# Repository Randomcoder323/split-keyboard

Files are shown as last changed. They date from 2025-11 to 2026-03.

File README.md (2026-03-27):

# split-keyboard

## Build!
This project was very fin to build, I had a few obstacles with the code and soldering, especially the battery. But in the end I finished and got it to work. Some keys don't fully work, but I really like how this turned out!





IMG_0612 (1)
IMG_0611 (1)

## Intro
Hello! This is my third blueprint project. After finishing the LED chaser and Hackpad, I wanted something more challenging. So I chose a keyboard. If you want to access my journals, here is the link:

[My Blueprint Journals](https://blueprint.hackclub.com/projects/1863)

---

## BOM Pictures






https://github.com/user-attachments/assets/b1c73c75-90e0-4224-99fa-895c186426c0





---

## CAD



<p align="center">
  CAD screenshot 1
</p>

<p align="center">
  CAD screenshot 2
</p>

---

## PCB + Schematics

<p align="center">
  PCB screenshot 1
</p>

<p align="center">
  PCB screenshot 2
</p>

<p align="center">
  PCB screenshot 3
</p>

---

## BOM Table

*to optimize cost and lower it i had to get 10 keyswitches fro aliexpress and rest from amazon to avoid payingg fro 70pc.

| Component | Cost (USD) | Link | Notes |
|---|---|---|---|
| PCB | 21.24 | https://jlcpcb.com | See screenshot in README |
| Seeed Studio XIAO x2 | 19.69 | https://www.aliexpress.us/item/3256808140543257.html | Free shipping; screenshots from AliExpress |
| Keycaps | 14.32 | https://www.aliexpress.us/item/3256809092009723.html | Free shipping |
| Switches | 26.26 | https://www.aliexpress.us/item/3256806440445666.html | Amazon + AliExpress |
| Amazon link for above |  | https://www.amazon.com/gp/product/B0FCYKV41M |  |
| Diodes | 0.99 | https://www.aliexpress.us/item/3256805857667344.html | Free shipping |
| Battery | 5.86 | https://www.aliexpress.us/item/3256808925051634.html | Free shipping |
| 3D printed parts | 0.00 | N/A | Shipped with another project |
| Resistors | 3.60 | https://www.aliexpress.us/item/3256806851785003.html | Three types, no shipping |
| Pins for MCU | 2.06 | https://www.aliexpress.us/item/2255800687544049.html | For the microcontroller |
| **Total** | **94.02** |  |  |

---

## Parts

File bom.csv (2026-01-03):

Component | Cost (USD) | Link | Notes
PCB | 21.24 | Jlcpcb.com | See screenshot in README
Seeed Studio XIAO x2 | 19.69 | https://www.aliexpress.us/item/3256808140543257.html?mp=1 | Free shipping; screenshots from AliExpress
Keycaps | 14.32 | https://www.aliexpress.us/item/3256809092009723.html?mp=1 | Free shipping
Switches | 26.26 | https://www.aliexpress.us/item/3256806440445666.html?mp=1 | Amazon + AliExpress
Amazon link for above |  | https://www.amazon.com/gp/product/B0FCYKV41M/ref=ox_sc_act_title_1?smid=A6078EBK4K8X5&psc=1
Diodes | 0.99 | https://www.aliexpress.us/item/3256805857667344.html?mp=1 | Free shipping
Battery | 5.86 | https://www.aliexpress.us/item/3256808925051634.html?curPageLogUid=C2q0nXbNds1O | Free shipping
3D printed parts | 0 | N/A | Shipped with another project
Resistors | 3.6 | https://www.aliexpress.us/item/3256806851785003.html?mp=1 | Three types, no shipping
Pins for MCU | 2.06 | https://www.aliexpress.us/item/2255800687544049.html?mp=1 | For the microcontroller
Total | 94.02

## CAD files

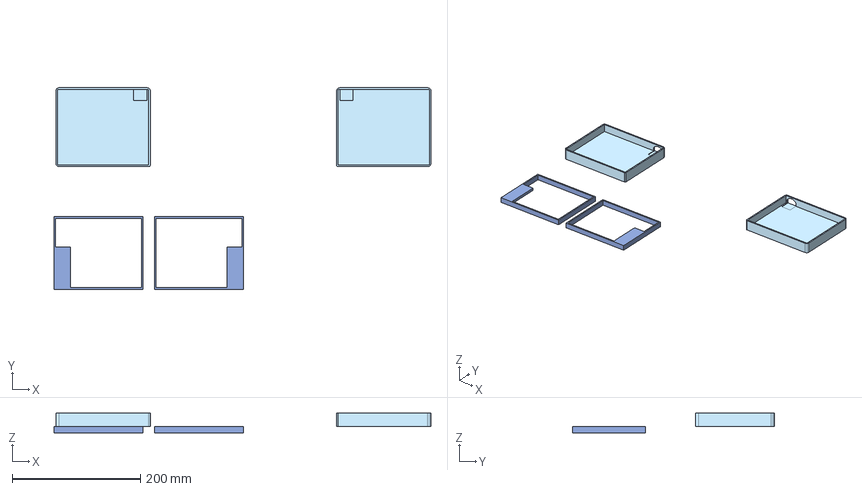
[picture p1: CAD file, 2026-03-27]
CAD/Keysplitcase.step
587.9 x 314.3 x 30.5 mm

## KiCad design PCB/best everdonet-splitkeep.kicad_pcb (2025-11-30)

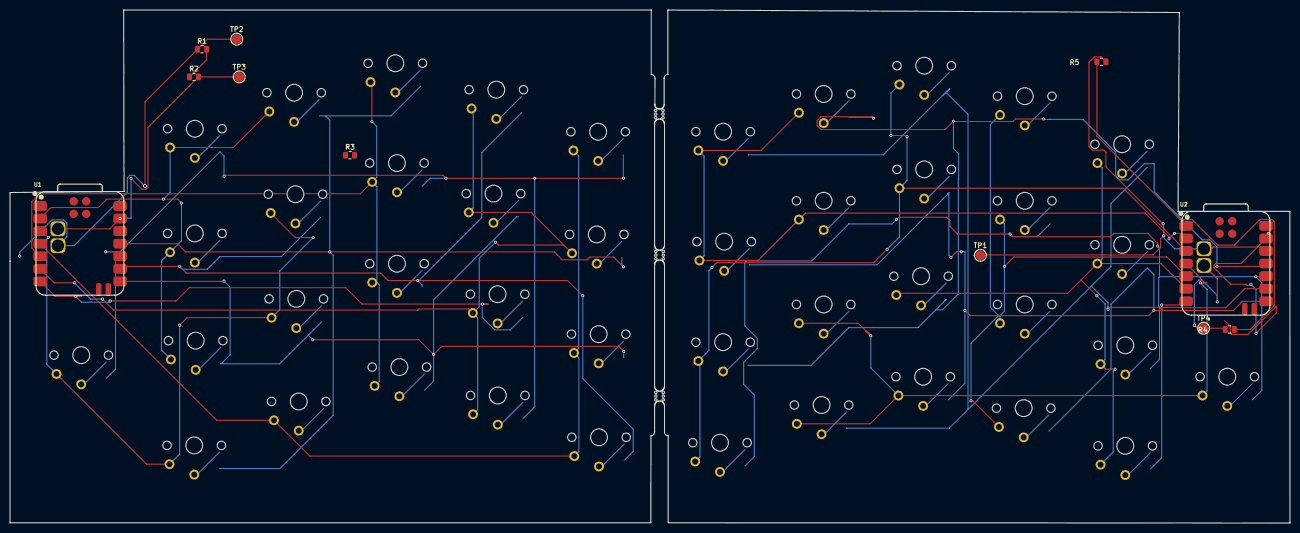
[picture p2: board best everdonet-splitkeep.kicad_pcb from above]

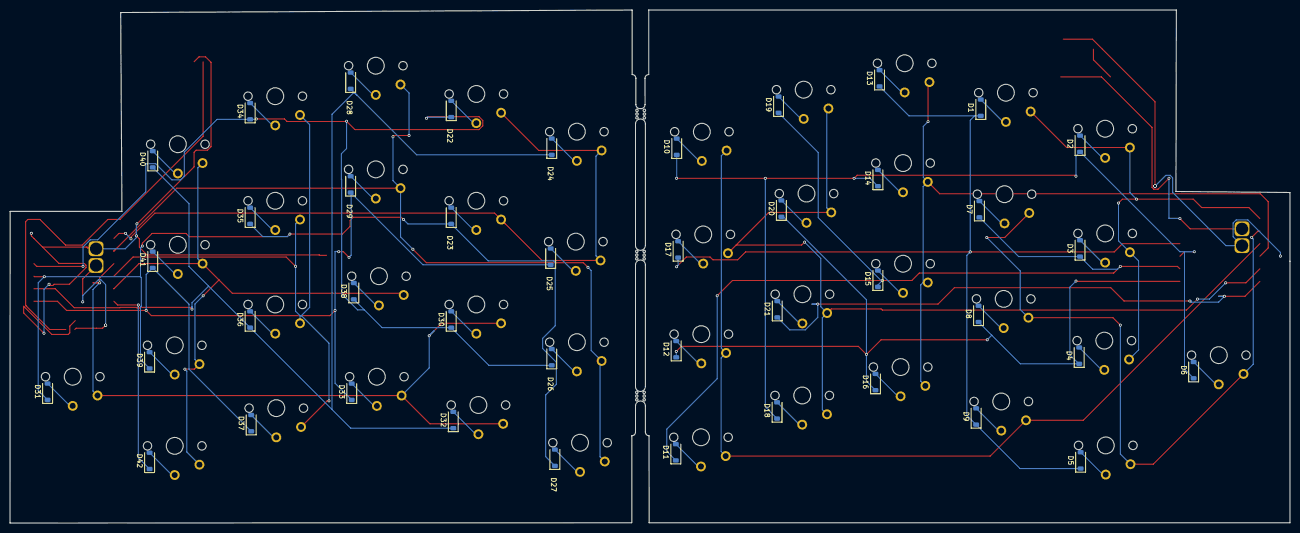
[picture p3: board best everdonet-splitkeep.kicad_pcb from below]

Board: 2 copper layers, 258.7 x 103.7 mm, 98 parts (42 on the bottom side), 67 nets.

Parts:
BO1, BO2, BO3: break off; mouse-bite-2mm-slot
D1, D2, D3, D4, D5, D6, D7, D8, D9, D10, D11, D12, D13, D14, D15, D16, D17, D18, D19, D20, D21, D22, D23, D24, D25, D26, D27, D28, D29, D30, D31, D32, D33, D34, D35, D36, D37, D38, D39, D40, D41, D42: D; D_SOD-123
R1, R4: 806k; R_0805_2012Metric
R2, R5: 2m; R_0805_2012Metric
R3: R; R_0805_2012Metric
SW1, SW2, SW3, SW4, SW5, SW6, SW7, SW8, SW9, SW10, SW11, SW12, SW13, SW14, SW15, SW16, SW17, SW18, SW19, SW20, SW21, SW22, SW23, SW24, SW25, SW26, SW27, SW28, SW29, SW30, SW31, SW32, SW33, SW34, SW35, SW36, SW37, SW38, SW39, SW40, SW41, SW42: SW_Push; SW_choc_v1_1u
TP1, TP2, TP3, TP4: TestPoint; TestPoint_Pad_D2.0mm
U1, U2: XIAO-nRF52840-SMD; modified-XIAO-nRF52840-SMD

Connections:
/left/BT-PIN: R1.2, R2.1
/left/C0: SW1.1, SW2.1, SW3.1, SW4.1, U1.2 (P0.03_A1_D1)
/left/C1: SW5.1, SW6.1, SW7.1, SW8.1, U1.3 (P0.28_A2_D2)
/left/C2: SW9.1, SW10.1, SW11.1, SW12.1, U1.4 (P0.29_A3_D3)
/left/C3: SW13.1, SW14.1, SW15.1, SW16.1, U1.5 (P0.04_A4_D4_SDA)
/left/C4: SW17.1, SW18.1, SW19.1, SW20.1, SW21.1, U1.6 (P0.05_A5_D5_SCL)
/left/R0: D1.1 (K), D5.1 (K), D9.1 (K), D13.1 (K), D17.1 (K), U1.11 (P1.15_D10_MOSI)
/left/R1: D2.1 (K), D6.1 (K), D10.1 (K), D14.1 (K), D18.1 (K), U1.10 (P1.14_D9_MISO)
/left/R4: D21.1 (K), U1.7 (P1.11_D6_TX)
/left/Ro2: D3.1 (K), D7.1 (K), D11.1 (K), D15.1 (K), D19.1 (K), U1.9 (P1.13_D8_SCK)
/left/Ro3: D4.1 (K), D8.1 (K), D12.1 (K), D16.1 (K), D20.1 (K), U1.8 (P1.12_D7_RX)
/left/VBAT: R1.1, TP2.1, U1.15 (BAT)
/right/BT-PIN: R4.2, R5.1
/right/C0: SW22.1, SW23.1, SW24.1, SW25.1, U2.2 (P0.03_A1_D1)
/right/C1: SW26.1, SW27.1, SW28.1, SW29.1, U2.3 (P0.28_A2_D2)
/right/C2: SW30.1, SW31.1, SW32.1, SW33.1, U2.4 (P0.29_A3_D3)
/right/C3: SW34.1, SW35.1, SW36.1, SW37.1, U2.5 (P0.04_A4_D4_SDA)
/right/C4: SW38.1, SW39.1, SW40.1, SW41.1, SW42.1, U2.6 (P0.05_A5_D5_SCL)
/right/R0: D22.1 (K), D26.1 (K), D30.1 (K), D34.1 (K), D38.1 (K), U2.11 (P1.15_D10_MOSI)
/right/R1: D23.1 (K), D27.1 (K), D31.1 (K), D35.1 (K), D39.1 (K), U2.10 (P1.14_D9_MISO)
/right/R4: D42.1 (K), U2.7 (P1.11_D6_TX)
/right/Ro2: D24.1 (K), D28.1 (K), D32.1 (K), D36.1 (K), D40.1 (K), U2.9 (P1.13_D8_SCK)
/right/Ro3: D25.1 (K), D29.1 (K), D33.1 (K), D37.1 (K), D41.1 (K), U2.8 (P1.12_D7_RX)
/right/VBAT: R4.1, TP4.1, U2.15 (BAT)
GND: R2.2, R5.2, TP1.1, TP3.1, U1.13 (GND), U1.16 (GND), U2.13 (GND), U2.16 (GND)
unnamed: D1.2 (A), SW1.2
unnamed: D2.2 (A), SW2.2
unnamed: D3.2 (A), SW3.2
unnamed: D4.2 (A), SW4.2
unnamed: D5.2 (A), SW5.2
unnamed: D6.2 (A), SW6.2
unnamed: D7.2 (A), SW7.2
unnamed: D8.2 (A), SW8.2
unnamed: D9.2 (A), SW9.2
unnamed: D10.2 (A), SW10.2
unnamed: D11.2 (A), SW11.2
unnamed: D12.2 (A), SW12.2
unnamed: D13.2 (A), SW13.2
unnamed: D14.2 (A), SW14.2
unnamed: D15.2 (A), SW15.2
unnamed: D16.2 (A), SW16.2
unnamed: D17.2 (A), SW17.2
unnamed: D18.2 (A), SW18.2
unnamed: D19.2 (A), SW19.2
unnamed: D20.2 (A), SW20.2
unnamed: D21.2 (A), SW21.2
unnamed: D22.2 (A), SW22.2
unnamed: D23.2 (A), SW23.2
unnamed: D24.2 (A), SW24.2
unnamed: D25.2 (A), SW25.2
unnamed: D26.2 (A), SW26.2
unnamed: D27.2 (A), SW27.2
unnamed: D28.2 (A), SW28.2
unnamed: D29.2 (A), SW29.2
unnamed: D30.2 (A), SW30.2
unnamed: D31.2 (A), SW31.2
unnamed: D32.2 (A), SW32.2
unnamed: D33.2 (A), SW33.2
unnamed: D34.2 (A), SW34.2
unnamed: D35.2 (A), SW35.2
unnamed: D36.2 (A), SW36.2
unnamed: D37.2 (A), SW37.2
unnamed: D38.2 (A), SW38.2
unnamed: D39.2 (A), SW39.2
unnamed: D40.2 (A), SW40.2
unnamed: D41.2 (A), SW41.2
unnamed: D42.2 (A), SW42.2

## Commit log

2025-11-30 Update and rename bom.CSV to bom.md
    [bom.CSV]
2025-11-30 Update and rename bom.md to bom.csv
    [bom.csv]
2025-12-17 Update and rename best everdonet-splitkeep.kicad_pcb to PCB/best everdonet-splitkeep.kicad_pcb
    [best everdonet-splitkeep.kicad_pcb]
2025-12-17 Rename best everdonet-splitkeep.kicad_pro to PCB/best everdonet-splitkeep.kicad_pro
2025-12-17 Update and rename best everdonet-splitkeep.kicad_sch to PCB/best everdonet-splitkeep.kicad_sch
    [best everdonet-splitkeep.kicad_sch]
